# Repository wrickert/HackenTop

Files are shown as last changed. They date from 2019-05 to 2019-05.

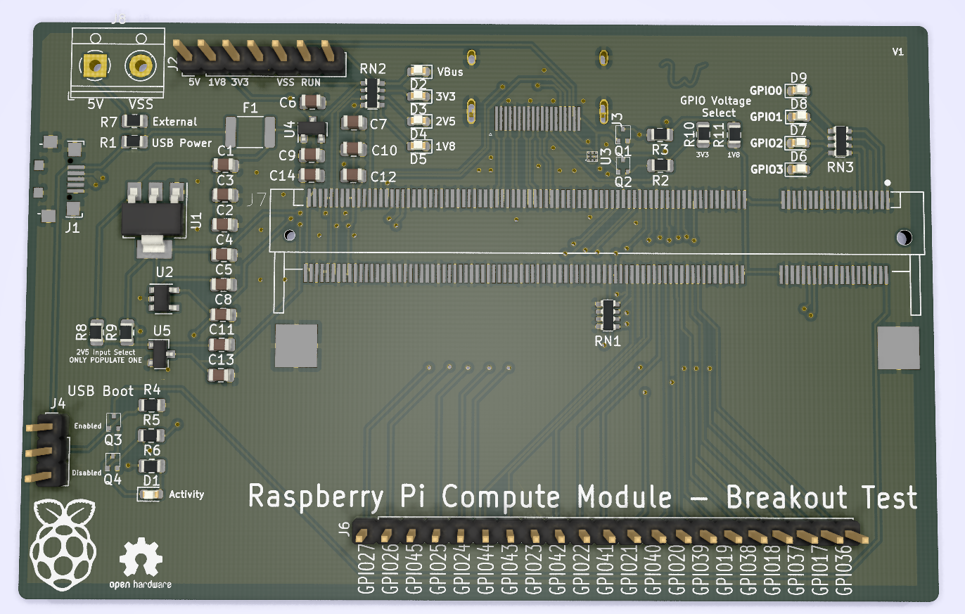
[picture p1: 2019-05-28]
Documents/V1.png

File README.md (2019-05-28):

The goal here is to create a low cost laptop inspired in the was as Andrew 'Bunnie' Huang's Novena Laptop. It will be designed around the Raspberry Pi 3+ (CM3+) Compute Module. The idea is the allow easy upgrade as new compute modules are released. Monitor will be an external component to begin with.

V1

22May - I returned to this project after nearly a year. The power requirements that looked daunting don't seem so bad now. <br>
26May - Completed first breakout board and ordered from JCLPCB<br>

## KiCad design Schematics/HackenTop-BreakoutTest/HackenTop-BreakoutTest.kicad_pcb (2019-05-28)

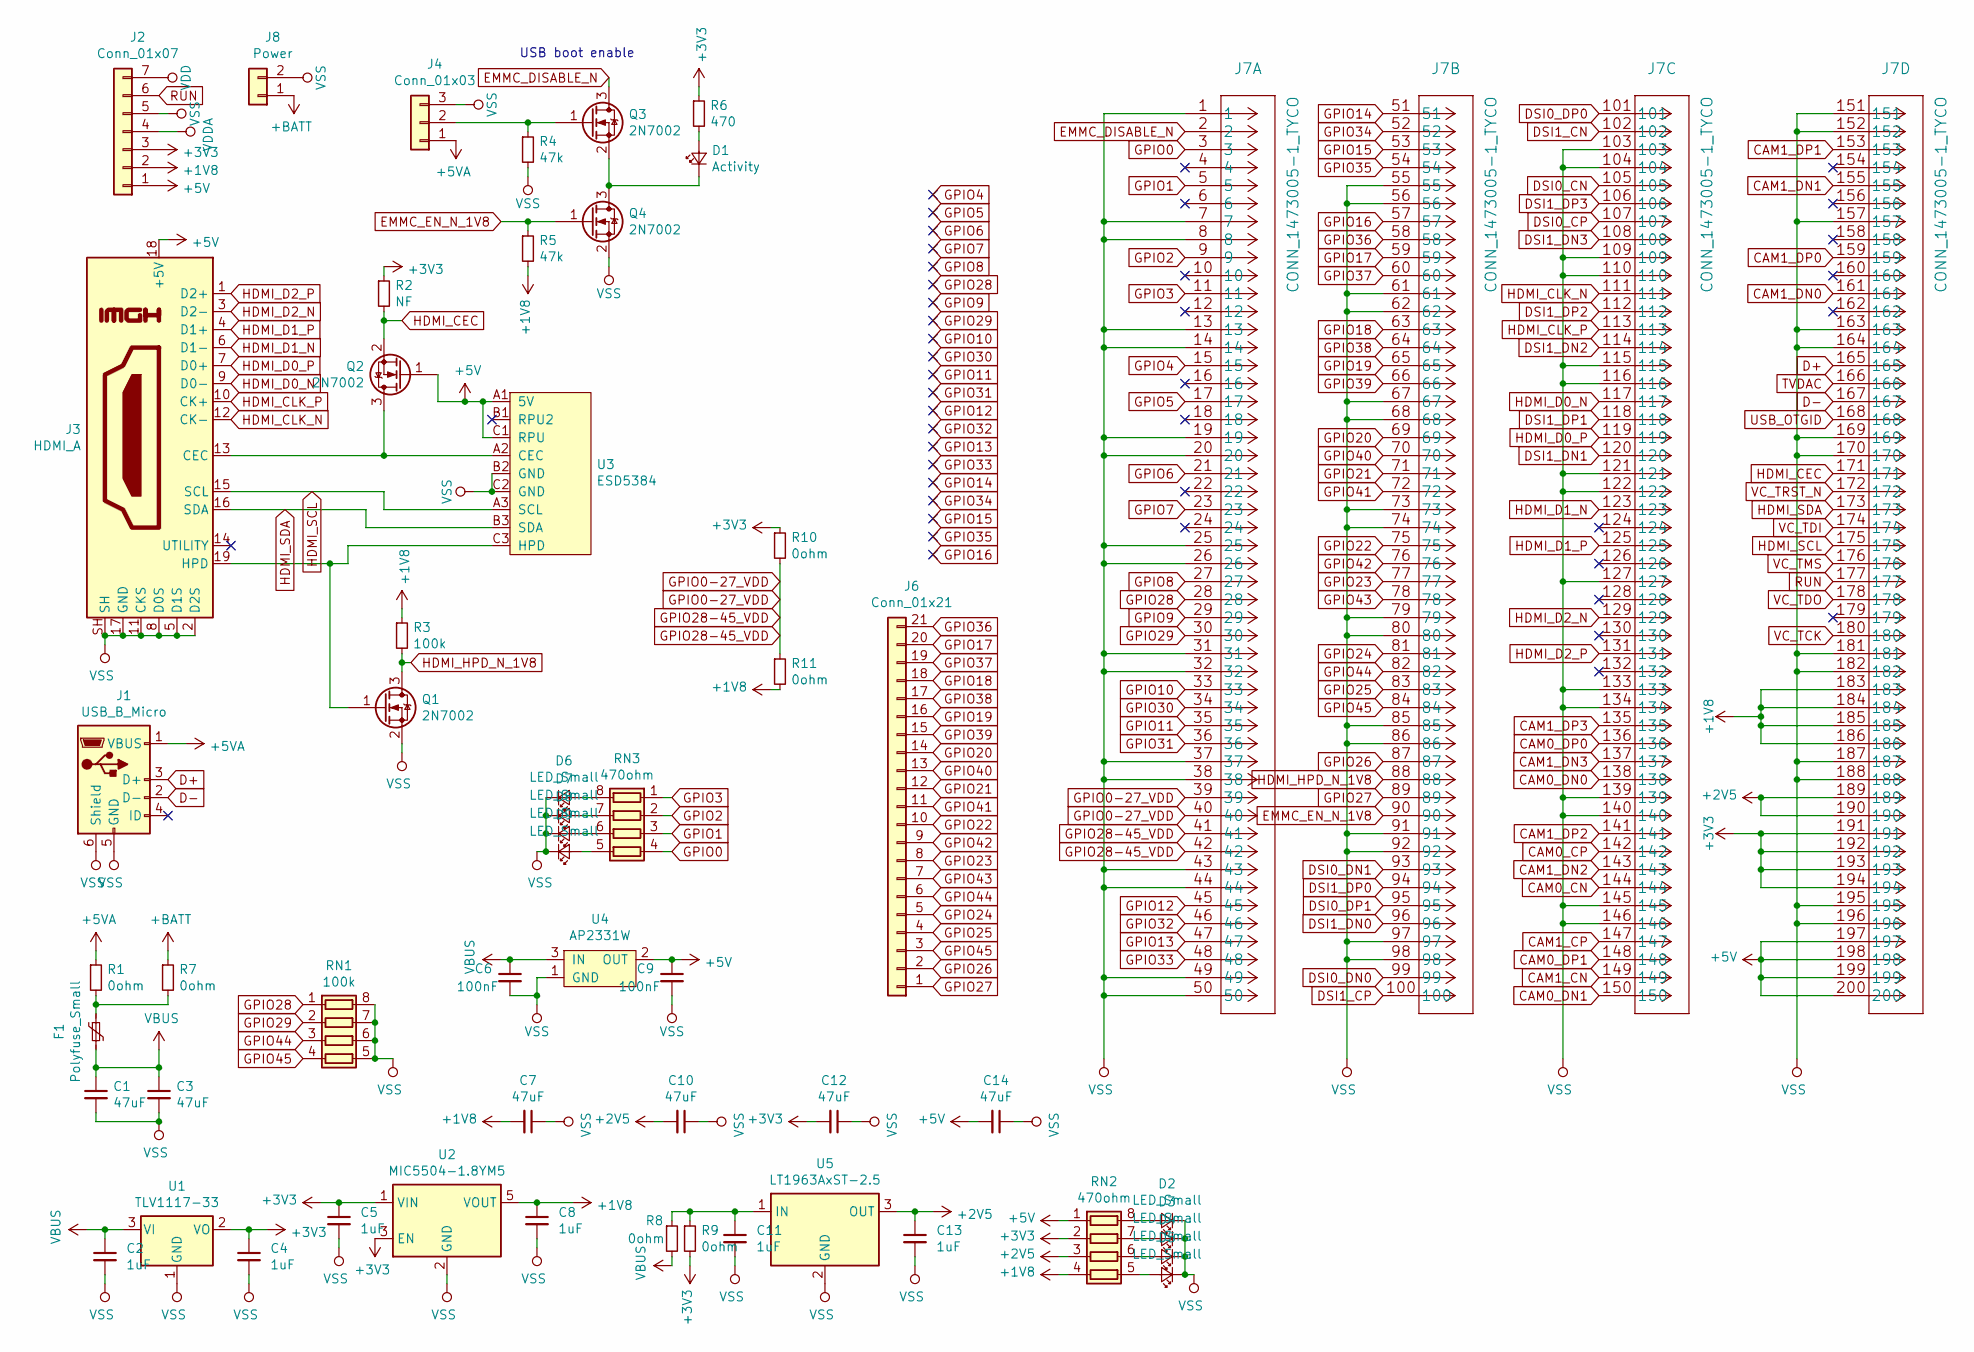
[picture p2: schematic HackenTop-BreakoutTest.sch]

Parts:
C1, C3, C7, C10, C12, C14: 47uF; C_0805_2012Metric
C2, C4, C5, C8, C11, C13: 1uF; C_0805_2012Metric
C6, C9: 100nF; C_0805_2012Metric
D1: Activity; LED_0603_1608Metric
D2, D3, D4, D5, D6, D7, D8, D9: LED_Small; LED_0603_1608Metric
F1: Polyfuse_Small; Fuse_1812_4532Metric
J1: USB_B_Micro; USB_Micro-B_Jing
J2: Conn_01x07; PinHeader_1x07_P2.54mm_Vertical
J3: HDMI_A; HDMI-jing
J4: Conn_01x03; PinHeader_1x03_P2.54mm_Vertical
J6: Conn_01x21; PinHeader_1x21_P2.54mm_Vertical
J7: CONN_1473005-1_TYCO; TE_1473149-4
J8: Power; TerminalBlock_RND_205-00012_1x02_P5.00mm_Horizontal
Q1, Q2, Q3, Q4: 2N7002; DMG1012T
R1, R7, R8, R9, R10, R11: 0ohm; R_0805_2012Metric
R2: NF; R_0805_2012Metric
R3: 100k; R_0805_2012Metric
R4, R5: 47k; R_0805_2012Metric
R6: 470; R_0805_2012Metric
RN1: 100k; R_Array_Convex_4x0603
RN2, RN3: 470ohm; R_Array_Convex_4x0603
U1: TLV1117-33; SOT-223-3_TabPin2
U2: MIC5504-1.8YM5; SOT-23-5
U3: ESD5384
U4: AP2331W; SOT-23
U5: LT1963AxST-2.5; SOT-23

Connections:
+1V8: C7.2, C8.1, J2.2, J7.183, J7.184, J7.185, J7.186, R3.1, R5.2, R11.2, RN2.4 (R4.1), U2.5 (VOUT)
+2V5: C10.2, C13.1, J7.189, J7.190, RN2.3 (R3.1), U5.3 (OUT)
+3V3: C4.1, C5.1, C12.2, J2.3, J7.191, J7.192, J7.193, J7.194, R2.1, R6.1, R9.2, R10.1, RN2.2 (R2.1), U1.2 (VO), U2.1 (VIN), U2.3 (EN)
+5V: C9.1, C14.2, J2.1, J3.18 (+5V), J7.197, J7.198, J7.199, J7.200, Q2.1 (G), RN2.1 (R1.1), U3.A1 (5V), U3.C1 (RPU), U4.2 (OUT)
+5VA: J1.1 (VBUS), J4.1, R1.1
+BATT: J8.1, R7.1
CAM0_CN: J7.144
CAM0_CP: J7.142
CAM0_DN0: J7.138
CAM0_DN1: J7.150
CAM0_DP0: J7.136
CAM0_DP1: J7.148
CAM1_CN: J7.149
CAM1_CP: J7.147
CAM1_DN0: J7.161
CAM1_DN1: J7.155
CAM1_DN2: J7.143
CAM1_DN3: J7.137
CAM1_DP0: J7.159
CAM1_DP1: J7.153
CAM1_DP2: J7.141
CAM1_DP3: J7.135
D+: J1.3 (D+), J7.165
D-: J1.2 (D-), J7.167
DSI0_CN: J7.105
DSI0_CP: J7.107
DSI0_DN0: J7.99
DSI0_DN1: J7.93
DSI0_DP0: J7.101
DSI0_DP1: J7.95
DSI1_CN: J7.102
DSI1_CP: J7.100
DSI1_DN0: J7.96
DSI1_DN1: J7.120
DSI1_DN2: J7.114
DSI1_DN3: J7.108
DSI1_DP0: J7.94
DSI1_DP1: J7.118
DSI1_DP2: J7.112
DSI1_DP3: J7.106
EMMC_DISABLE_N: J7.2, Q3.3 (D)
EMMC_EN_N_1V8: J7.90, Q4.1 (G), R5.1
GPIO0: J7.3, RN3.4 (R4.1)
GPIO0-27_VDD: J7.39, J7.40, J7.41, J7.42, R10.2, R11.1
GPIO1: J7.5, RN3.3 (R3.1)
GPIO2: J7.9, RN3.2 (R2.1)
GPIO3: J7.11, RN3.1 (R1.1)
GPIO4: J7.15
GPIO5: J7.17
GPIO6: J7.21
GPIO7: J7.23
GPIO8: J7.27
GPIO9: J7.29
GPIO10: J7.33
GPIO11: J7.35
GPIO12: J7.45
GPIO13: J7.47
GPIO14: J7.51
GPIO15: J7.53
GPIO16: J7.57
GPIO17: J6.20, J7.59
GPIO18: J6.18, J7.63
GPIO19: J6.16, J7.65
GPIO20: J6.14, J7.69
GPIO21: J6.12, J7.71
GPIO22: J6.10, J7.75
GPIO23: J6.8, J7.77
GPIO24: J6.5, J7.81
GPIO25: J6.4, J7.83
GPIO26: J6.2, J7.87
GPIO27: J6.1, J7.89
GPIO28: J7.28, RN1.1 (R1.1)
GPIO29: J7.30, RN1.2 (R2.1)
GPIO30: J7.34
GPIO31: J7.36
GPIO32: J7.46
GPIO33: J7.48
GPIO34: J7.52
GPIO35: J7.54
GPIO36: J6.21, J7.58
GPIO37: J6.19, J7.60
GPIO38: J6.17, J7.64
GPIO39: J6.15, J7.66
GPIO40: J6.13, J7.70
GPIO41: J6.11, J7.72
GPIO42: J6.9, J7.76
GPIO43: J6.7, J7.78
GPIO44: J6.6, J7.82, RN1.3 (R3.1)
GPIO45: J6.3, J7.84, RN1.4 (R4.1)
HDMI_CEC: J7.171, Q2.2 (S), R2.2
HDMI_CLK_N: J3.12 (CK-), J7.111
HDMI_CLK_P: J3.10 (CK+), J7.113
HDMI_D0_N: J3.9 (D0-), J7.117
HDMI_D0_P: J3.7 (D0+), J7.119
HDMI_D1_N: J3.6 (D1-), J7.123
HDMI_D1_P: J3.4 (D1+), J7.125
HDMI_D2_N: J3.3 (D2-), J7.129
HDMI_D2_P: J3.1 (D2+), J7.131
HDMI_HPD_N_1V8: J7.88, Q1.3 (D), R3.2
HDMI_SCL: J3.15 (SCL), J7.175, U3.A3 (SCL)
HDMI_SDA: J3.16 (SDA), J7.173, U3.B3 (SDA)
unnamed: C11.1, R8.1, R9.1, U5.1 (IN)
unnamed: D1.1 (K), Q3.2 (S), Q4.3 (D)
unnamed: D1.2 (A), R6.2
unnamed: D2.2 (A), RN2.8 (R1.2)
unnamed: D3.2 (A), RN2.7 (R2.2)
unnamed: D4.2 (A), RN2.6 (R3.2)
unnamed: D5.2 (A), RN2.5 (R4.2)
unnamed: D6.2 (A), RN3.8 (R1.2)
unnamed: D7.2 (A), RN3.7 (R2.2)
unnamed: D8.2 (A), RN3.6 (R3.2)
unnamed: D9.2 (A), RN3.5 (R4.2)
unnamed: F1.1, R1.2, R7.2
unnamed: J3.13 (CEC), Q2.3 (D), U3.A2 (CEC)
unnamed: J3.19 (HPD), Q1.1 (G), U3.C3 (HPD)
unnamed: J4.2, Q3.1 (G), R4.1
RUN: J2.6, J7.177
TVDAC: J7.166; also elsewhere on the board
USB_OTGID: J7.168
VBUS: C1.1, C2.1, C3.1, C6.1, F1.2, R8.2, U1.3 (VI), U4.3 (IN)
VC_TCK: J7.180
VC_TDI: J7.174
VC_TDO: J7.178
VC_TMS: J7.176
VC_TRST_N: J7.172
VDD: J2.7
VDDA: J2.4
VSS: C1.2, C2.2, C3.2, C4.2, C5.2, C6.2, C7.1, C8.2, C9.2, C10.1, C11.2, C12.1, C13.2, C14.1, D2.1 (K), D3.1 (K), D4.1 (K), D5.1 (K), D6.1 (K), D7.1 (K), D8.1 (K), D9.1 (K), J1.5 (GND), J1.6 (Shield), J2.5, J3.2 (D2S), J3.5 (D1S), J3.8 (D0S), J3.11 (CKS), J3.17 (GND), J3.20, J3.21, J3.22, J3.23, J3.SH, J4.3, J7.1, J7.7, J7.8, J7.13, J7.14, J7.19, J7.20, J7.25, J7.26, J7.31, J7.32, J7.37, J7.38, J7.43, J7.44, J7.49, J7.50, J7.55, J7.56, J7.61, J7.62, J7.67, J7.68, J7.73, J7.74, J7.79, J7.80, J7.85, J7.86, J7.91, J7.92, J7.97, J7.98, J7.103, J7.104, J7.109, J7.110, J7.115, J7.116, J7.121, J7.122, J7.127, J7.133, J7.134, J7.139, J7.140, J7.145, J7.146, J7.151, J7.152, J7.157, J7.163, J7.164, J7.169, J7.170, J7.181, J7.182, J7.187, J7.188, J7.195, J7.196, J7.SH1, J7.SH2, J8.2, Q1.2 (S), Q4.2 (S), R4.2, RN1.5 (R4.2), RN1.6 (R3.2), RN1.7 (R2.2), RN1.8 (R1.2), U1.1 (GND), U2.2 (GND), U3.B2 (GND), U3.C2 (GND), U4.1 (GND), U5.2 (GND); also elsewhere on the board

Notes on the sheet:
USB boot enable

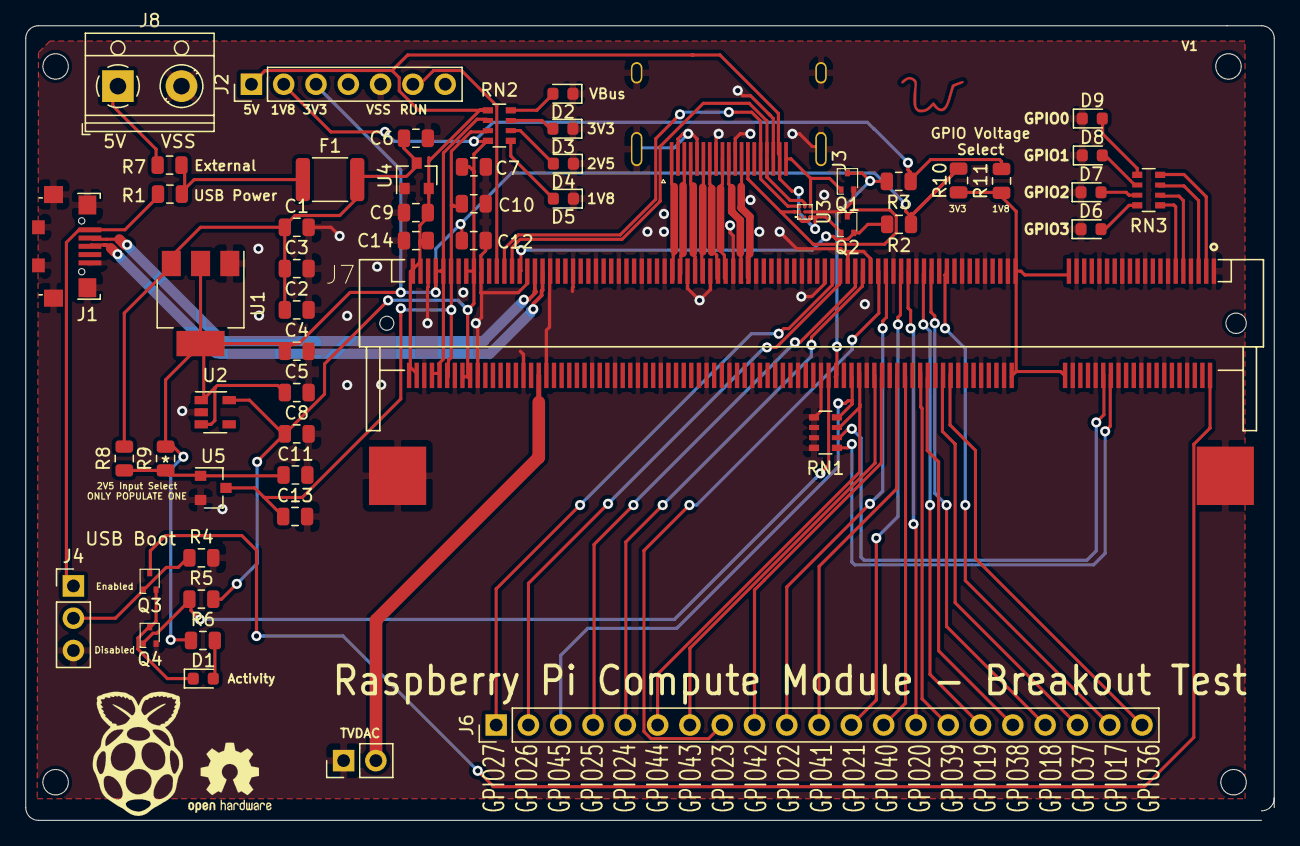
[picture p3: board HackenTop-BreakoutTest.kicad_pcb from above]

Board: 2 copper layers, 98.2 x 62.5 mm, 57 parts (0 on the bottom side), 69 nets.

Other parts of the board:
Ref**: Val**; raspberry
Ref**#2: Val**; W
TVDAC: PinHeader_1x02_P2.54mm_Vertical

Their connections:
TVDAC: TVDAC.2; also elsewhere on the board
VSS: TVDAC.1; also elsewhere on the board

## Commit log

2019-05-25 Reorganized file structure and added to schematic
    [HackenTop-BreakoutTest-2019-05-24-15-52-03.sch, HackenTop-BreakoutTest.kicad_pcb, HackenTop-BreakoutTest.sch]
2019-05-26 Starting routing
    [HackenTop-BreakoutTest.sch]
2019-05-28 V1 ordered May26
    [HackenTop-BreakoutTest-B_Cu.gbr, HackenTop-BreakoutTest-B_Mask.gbr, HackenTop-BreakoutTest-B_Paste.gbr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]
